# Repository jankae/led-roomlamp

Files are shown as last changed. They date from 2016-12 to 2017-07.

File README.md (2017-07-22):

# led-roomlamp
The led-roomlamp consists of up to six LED spots connected to a central baseplate.
<p align="left">
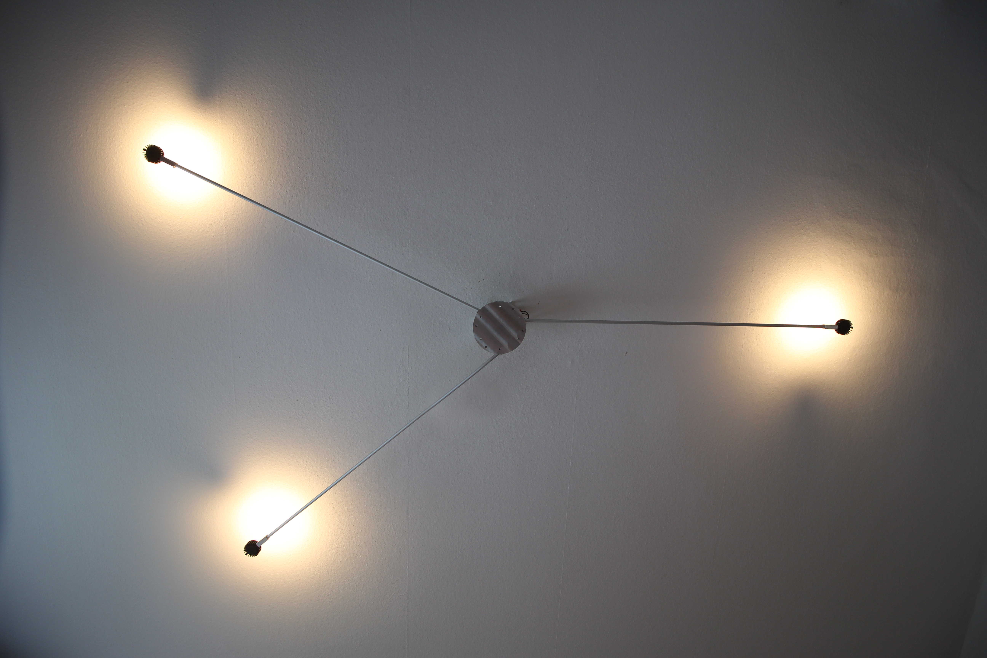
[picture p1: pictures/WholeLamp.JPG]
  
</p>

Each spot features a 10W LED on a heatsink with its own (AVR controller) boost-converter (led-driver):
<p align="left">
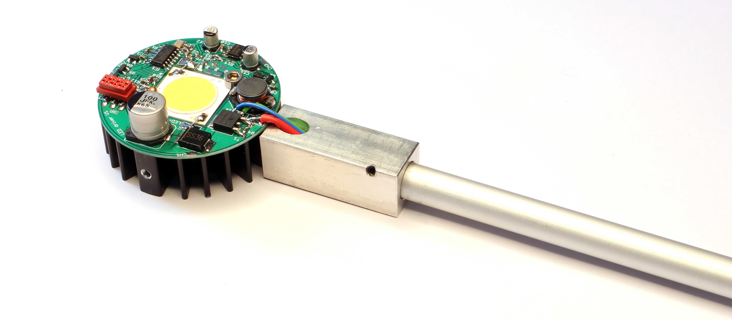
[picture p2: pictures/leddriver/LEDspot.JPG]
  
</p>
The spot needs a 12V supply and can be controlled via I2C. All the spots are connected to the central led-control board on the baseplate:
<p align="left">
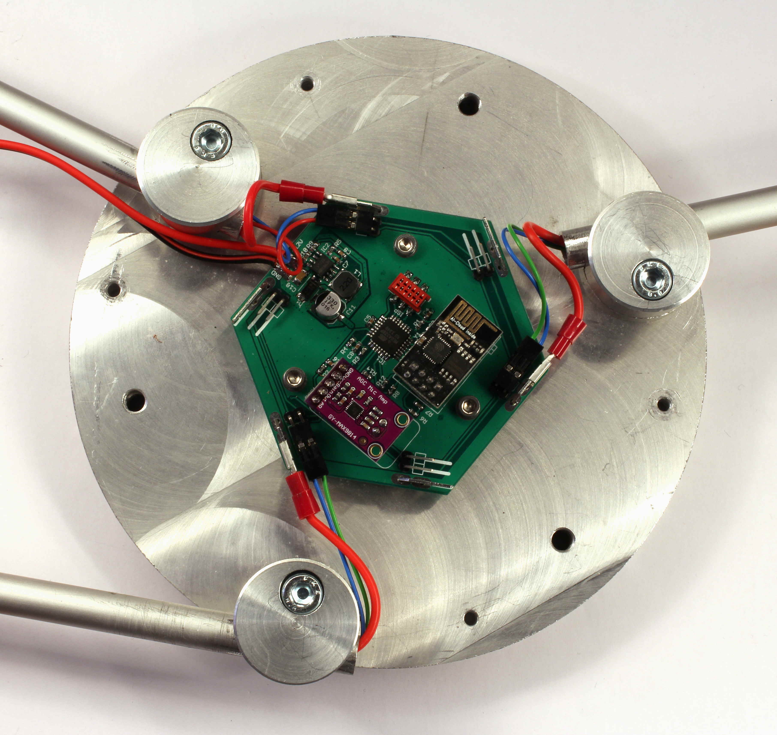
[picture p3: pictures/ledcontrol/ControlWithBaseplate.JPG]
  
</p>
The led-control board essentially is just an ATmega328 with a switching controller, a microphone (one of the available MAX9814 breakout-boards) and (optionally) an ESP-01.

The controller continuously samples the microphone, performs an FFT and identifies whistle tones. By whistling different frequencies, the brightness of the lamp can be controlled.

Alternatively, the lamp can be controlled via UART (38400 Baud) which is connected to the ESP. Using the [ESP-link](https://github.com/jeelabs/esp-link) firmware, commands can be send via WiFi. Send 'help' to retrieve a list of available commands.

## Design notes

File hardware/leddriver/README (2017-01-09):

As usual, the first revision (V1) of the board includes some mistakes.
These are the necessary fixes (see fixesV1.JPG):

1. Do not populate R2.
2. Do not populate R14.
3. Do not populate Q3. Instead short its base and collector and add a resistor of approx. 10k between the emitter and collector.
4. Add a 100nF capacitor from IC1 pin 13 to ground.
5. Add a 100nF capacitor on top of R9.
6. Add a 100nF capacitor on top of R12.
7. Add a 1k resistor from R15 to ground.

These are fixed in V1.1. But since V1 is working well, V1.1 will probably never be build, is therefore untested and might contain further errors.

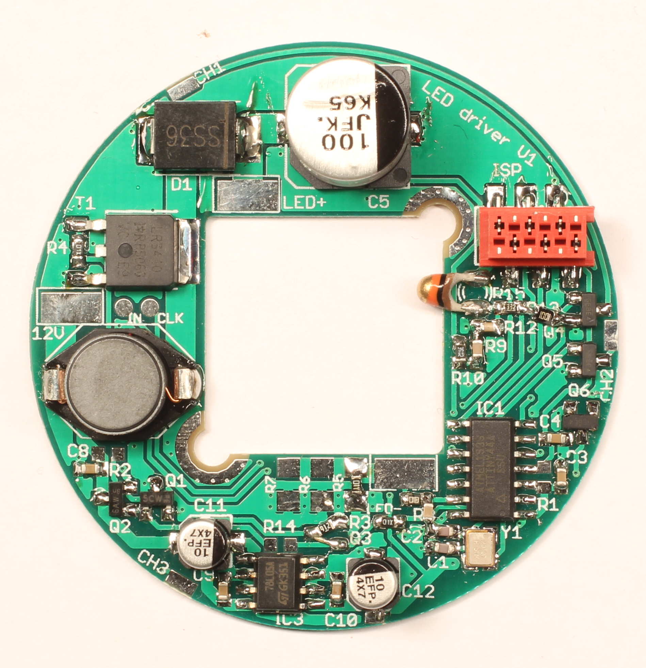
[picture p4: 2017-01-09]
pictures/leddriver/leddriverV1.JPG

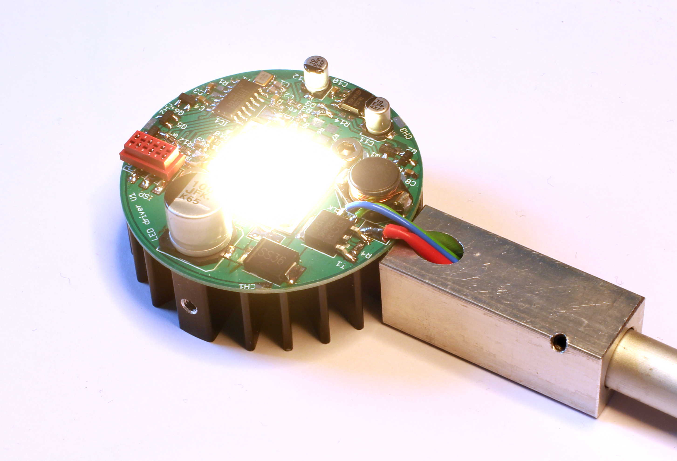
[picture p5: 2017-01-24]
pictures/leddriver/LEDon.JPG

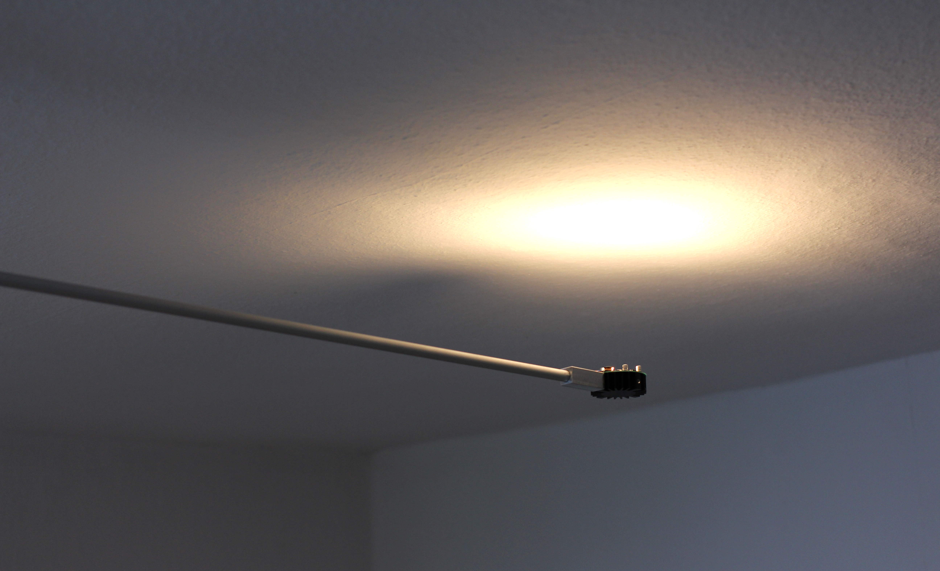
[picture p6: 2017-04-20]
pictures/Spot.JPG

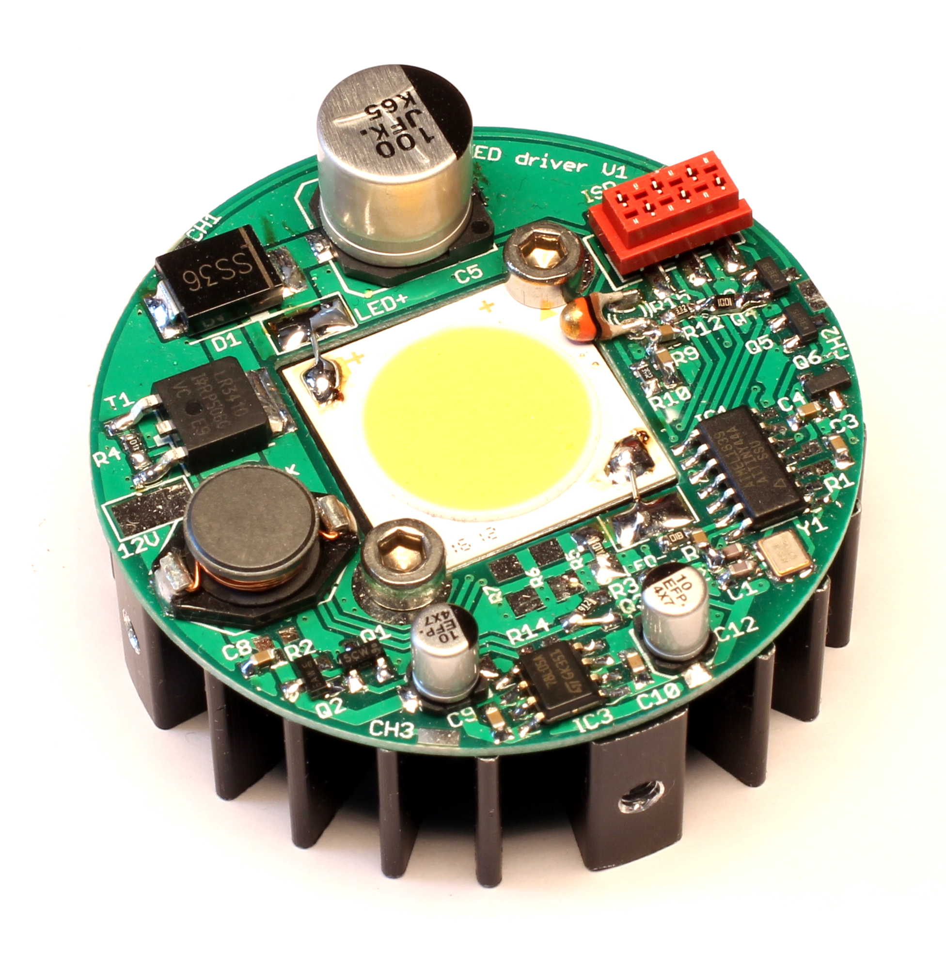
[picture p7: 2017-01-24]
pictures/leddriver/PCBonHeatsink.JPG

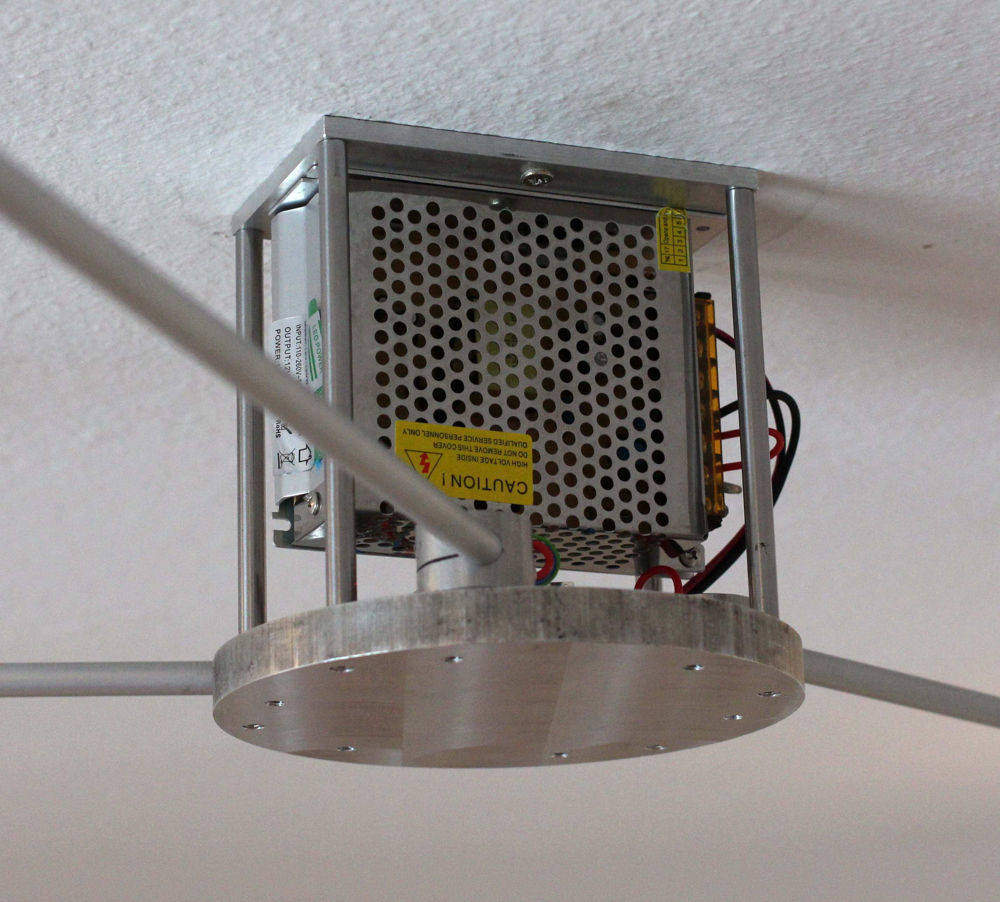
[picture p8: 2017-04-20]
pictures/Base.JPG

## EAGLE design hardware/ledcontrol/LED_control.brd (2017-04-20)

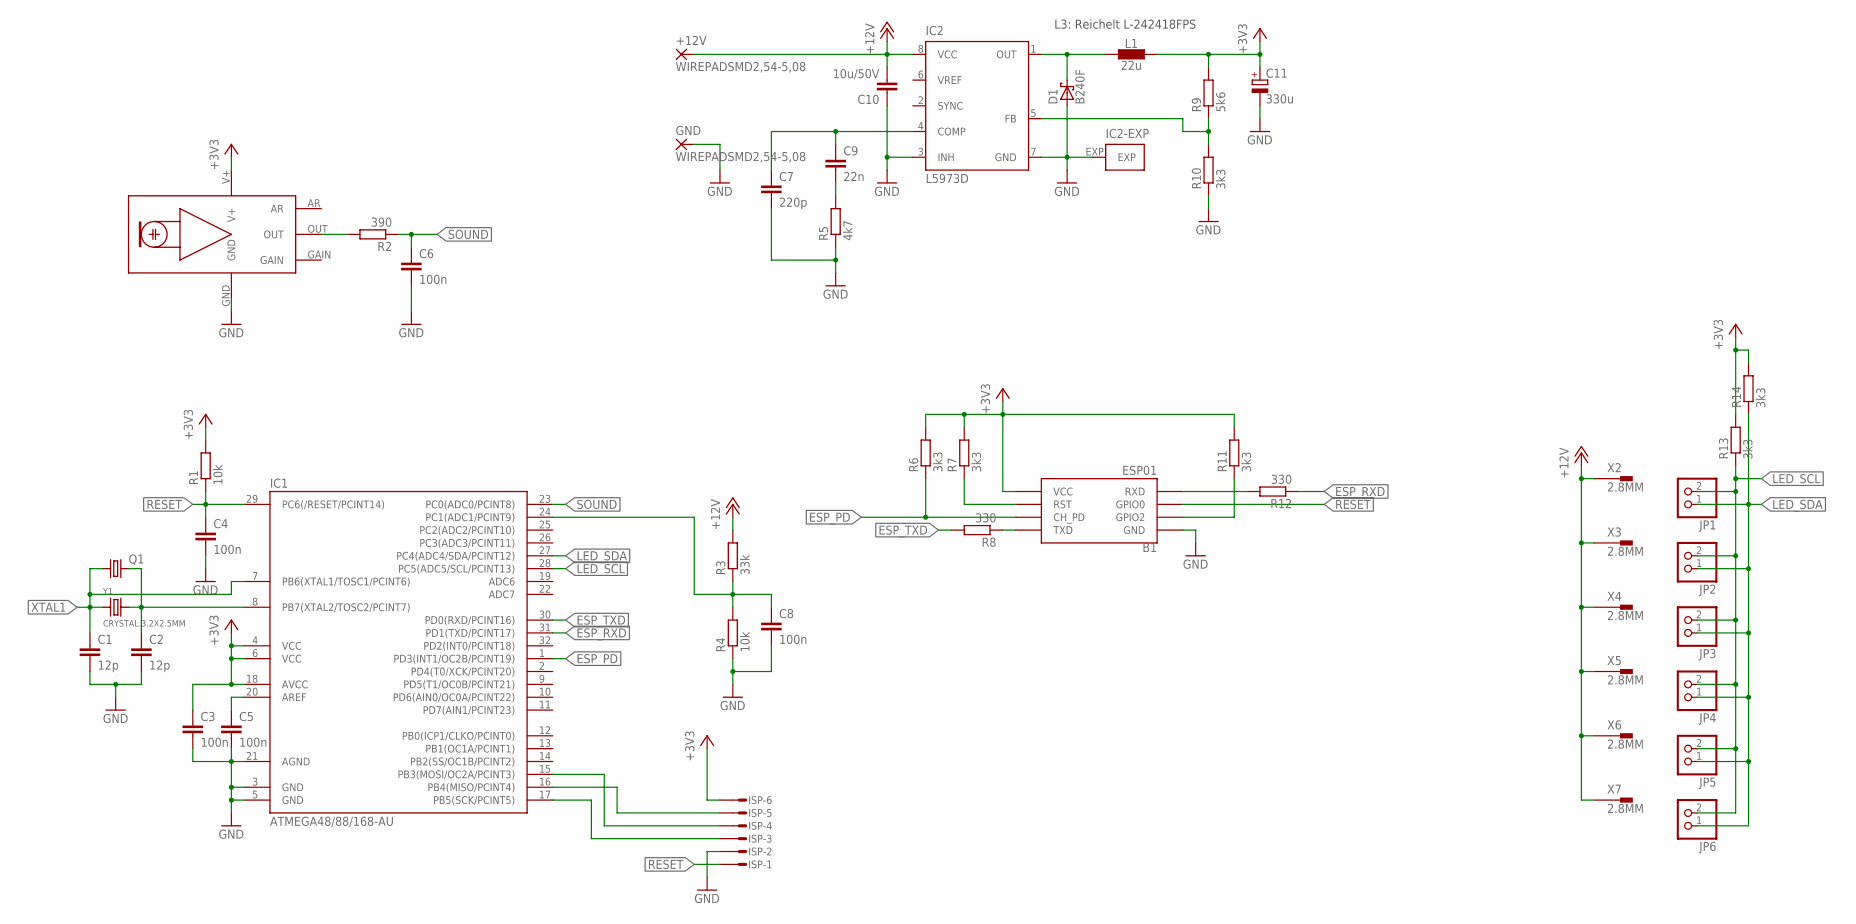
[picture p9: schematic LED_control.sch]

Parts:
+12V: WIREPADSMD2,54-5,08; SMD2,54-5,08
B1: ESP01
C1, C2: 12p; C0603K
C3, C5, C6: 100n; C0603K
C4, C8: 100n; C0603
C7: 220p; C0603
C9: 22n; C0603
C10: 10u/50V; C1206
C11: 330u; 153CLV-0605
D1: B240F; SMB
GND: WIREPADSMD2,54-5,08; SMD2,54-5,08
IC1: ATMEGA48/88/168-AU; TQFP32-08
IC2: L5973D; HSOP8
ISP: MICROMATCH-6SMF; MMT-F-SMD-6
JP1, JP2, JP3, JP4, JP5, JP6: PINHD-1X2/90; 1X02/90
L1: 22u; L_NR60XX
PCB1: MAX9814_AGC_MIC
Q1: CRYSTALHC49S; HC49/S
R1, R4: 10k; R0603
R2: 390; R0603
R3: 33k; R0603
R5: 4k7; R0603
R6, R7, R10, R11, R13, R14: 3k3; R0603
R8, R12: 330; R0603
R9: 5k6; R0603
X2, X3, X4, X5, X6, X7: 2.8MM; 2.8_90
Y1: CRYSTAL.3.2X2.5MM; 3.2X2.5MM

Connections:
+3V3: B1.VCC, C3.1, C11.+, IC1.4 (VCC), IC1.6 (VCC), IC1.18 (AVCC), ISP.6, L1.2, PCB1.V+, R1.2, R6.2, R7.2, R9.2, R11.2, R13.2, R14.2
+12V: +12V.1, C10.2, IC2.8 (VCC), R3.2, X2.1A, X2.1B, X3.1A, X3.1B, X4.1A, X4.1B, X5.1A, X5.1B, X6.1A, X6.1B, X7.1A, X7.1B
ESP_GPIO2: B1.GPIO2, R11.1
ESP_PD: B1.CH_PD, IC1.1 (PD3(INT1/OC2B/PCINT19)), R6.1
ESP_RST: B1.RST, R7.1
ESP_RXD: IC1.31 (PD1(TXD/PCINT17)), R12.1
ESP_TXD: IC1.30 (PD0(RXD/PCINT16)), R8.2
GND: B1.GND, C1.2, C2.2, C3.2, C4.2, C5.2, C6.2, C7.2, C8.2, C10.1, C11.-, D1.A, GND.1, IC1.3 (GND), IC1.5 (GND), IC1.21 (AGND), IC2.3 (INH), IC2.7 (GND), IC2.EXP, ISP.2, PCB1.GND, R4.1, R5.1, R10.1
LED_SCL: IC1.28 (PC5(ADC5/SCL/PCINT13)), JP1.2, JP2.2, JP3.2, JP4.2, JP5.2, JP6.2, R13.1
LED_SDA: IC1.27 (PC4(ADC4/SDA/PCINT12)), JP1.1, JP2.1, JP3.1, JP4.1, JP5.1, JP6.1, R14.1
MISO: IC1.16 (PB4(MISO/PCINT4)), ISP.5
MOSI: IC1.15 (PB3(MOSI/OC2A/PCINT3)), ISP.4
unnamed: B1.RX (RXD), R12.2
unnamed: B1.TX (TXD), R8.1
unnamed: C5.1, IC1.20 (AREF)
unnamed: PCB1.OUT, R2.2
unnamed: C8.1, IC1.24 (PC1(ADC1/PCINT9)), R3.1, R4.2
unnamed: C7.1, C9.1, IC2.4 (COMP)
unnamed: C9.2, R5.2
unnamed: D1.C, IC2.1 (OUT), L1.1
unnamed: IC2.5 (FB), R9.1, R10.2
RESET: B1.GPIO0, C4.1, IC1.29 (PC6(/RESET/PCINT14)), ISP.1, R1.1
SCK: IC1.17 (PB5(SCK/PCINT5)), ISP.3
SOUND: C6.1, IC1.23 (PC0(ADC0/PCINT8)), R2.1
XTAL1: C1.1, IC1.7 (PB6(XTAL1/TOSC1/PCINT6)), Q1.1, Y1.1
XTAL2: C2.1, IC1.8 (PB7(XTAL2/TOSC2/PCINT7)), Q1.2, Y1.3 (2)

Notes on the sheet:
L3: Reichelt L-242418FPS

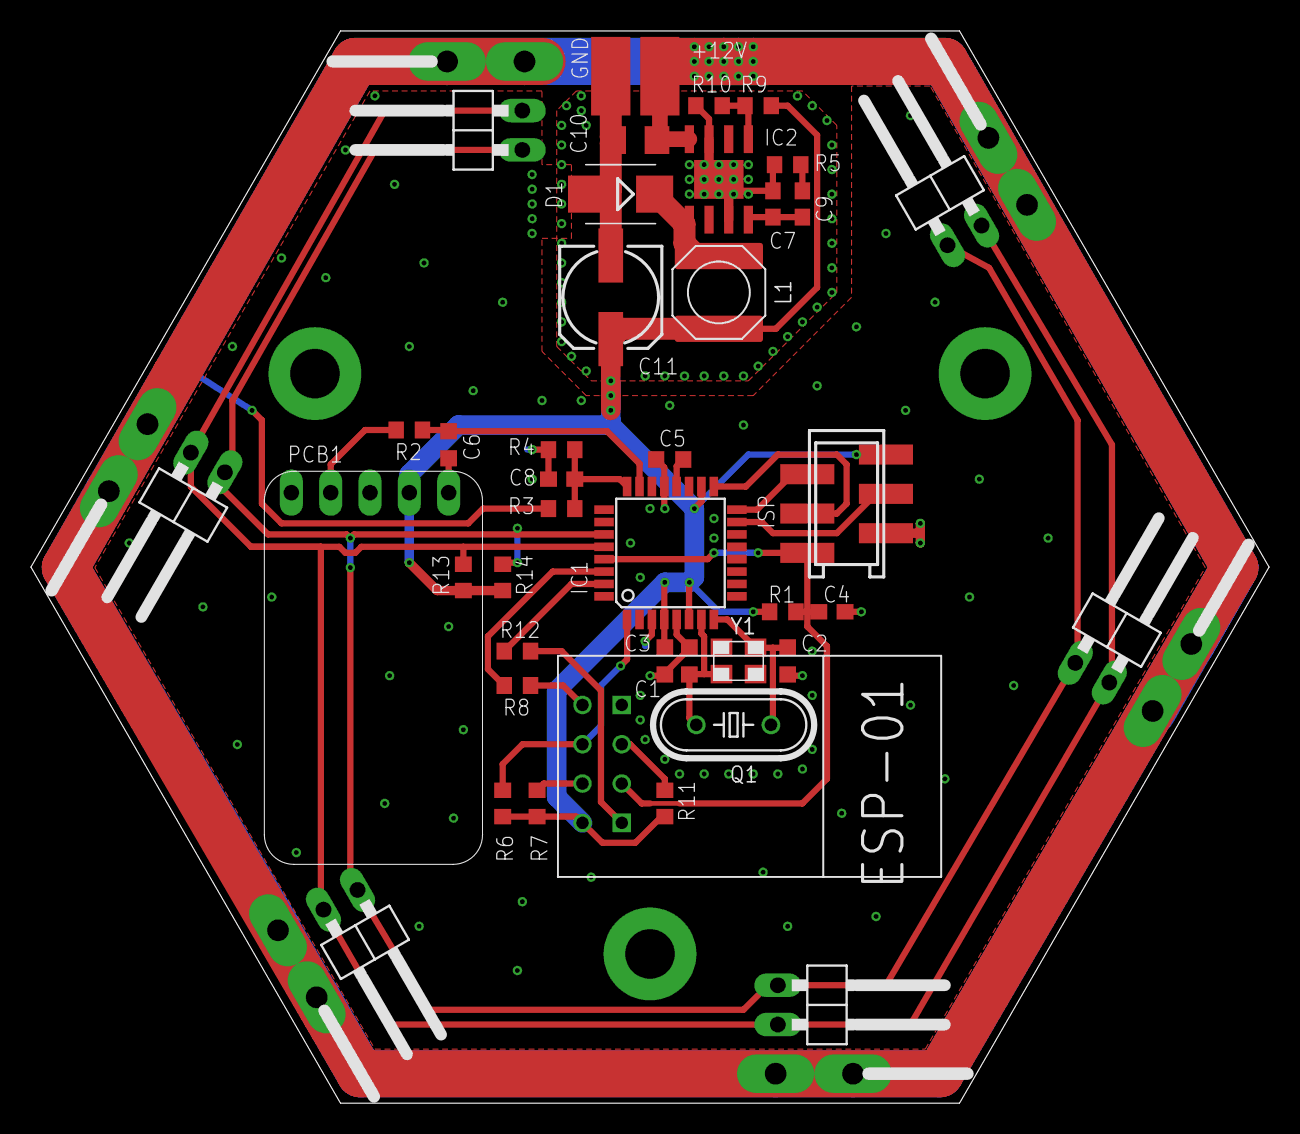
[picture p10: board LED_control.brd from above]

Board: 2 copper layers, 80.0 x 69.3 mm, 48 parts (0 on the bottom side), 26 nets.

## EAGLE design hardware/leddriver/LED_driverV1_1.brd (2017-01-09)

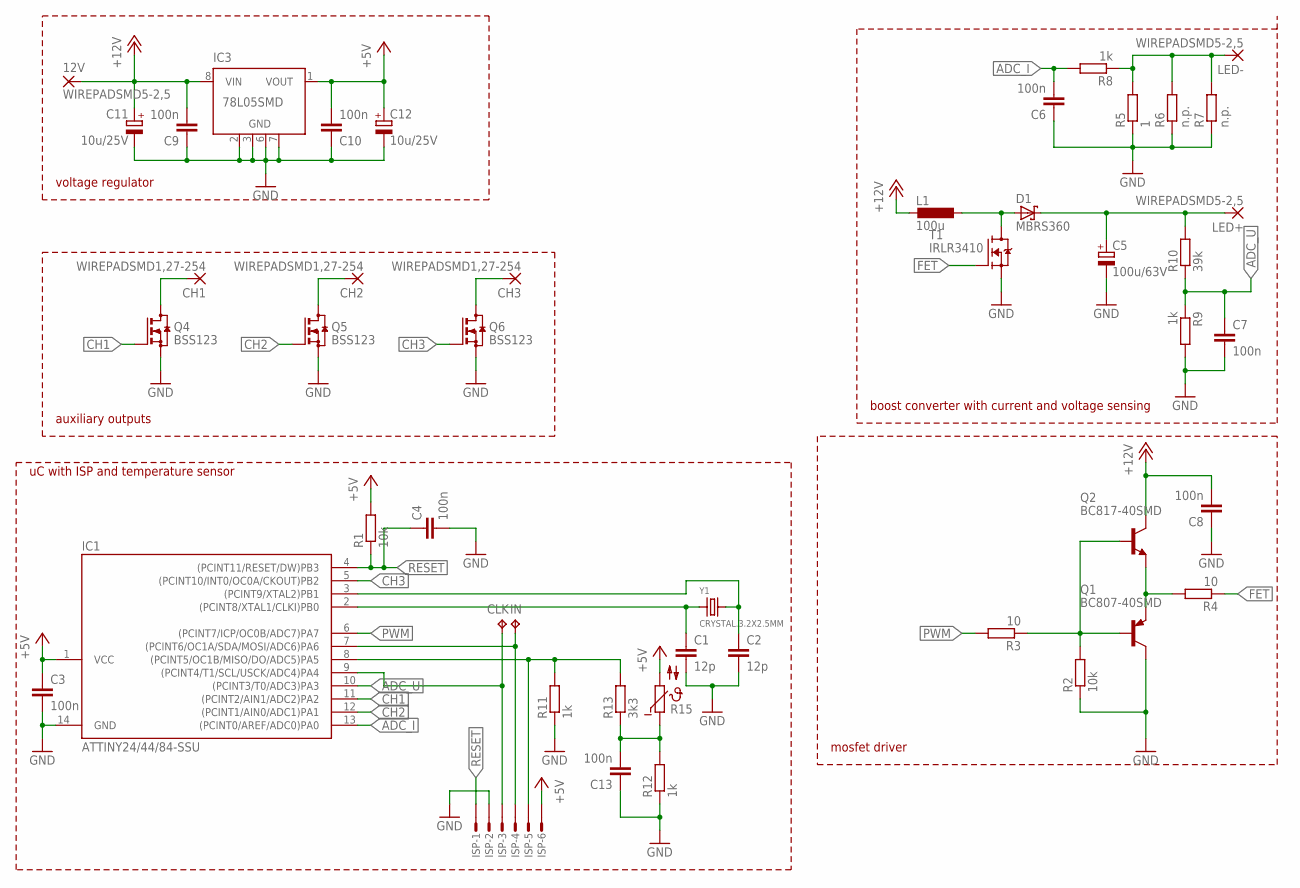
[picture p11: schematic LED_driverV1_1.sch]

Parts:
12V: WIREPADSMD5-2,5; 5-2,5
C1, C2: 12p; C0603K
C3, C4, C6, C7, C8, C9, C10, C13: 100n; C0603K
C5: 100u/63V; 153CLV-1010
C11, C12: 10u/25V; 153CLV-0405
CH1, CH2, CH3: WIREPADSMD1,27-254; SMD1,27-2,54
CLK: TPTP15R; TP15R
D1: MBRS360; SMC
IC1: ATTINY24/44/84-SSU; SOIC14
IC3: 78L05SMD; SO08
IN: TPTP15R; TP15R
ISP: MICROMATCH-6SMF; MMT-F-SMD-6
L1: 100u; PISM
LED+: WIREPADSMD5-2,5; 5-2,5
LED-: WIREPADSMD5-2,5; 5-2,5
Q1: BC807-40SMD; SOT23-BEC
Q2: BC817-40SMD; SOT23-BEC
Q4, Q5, Q6: BSS123; SOT23
R1, R2: 10k; R0603
R3, R4: 10; R0603
R5: 1; R1206
R6, R7: n.p.; R1206
R8, R9, R11, R12: 1k; R0603
R10: 39k; R0603
R13: 3k3; R0603
R15: NTC640; P640
T1: IRLR3410; TO252
Y1: CRYSTAL.3.2X2.5MM; 3.2X2.5MM

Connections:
+5V: C3.1, C10.2, C12.+, IC1.1 (VCC), IC3.1 (VOUT), ISP.6, R1.2, R15.2
+12V: 12V.1, C8.2, C9.2, C11.+, IC3.8 (VIN), L1.2, Q2.C
ADC_I: C6.2, IC1.13 ((PCINT0/AREF/ADC0)PA0), R8.2
ADC_U: C7.1, IC1.10 ((PCINT3/T0/ADC3)PA3), R9.1, R10.1
CH1: IC1.11 ((PCINT2/AIN1/ADC2)PA2), Q4.1 (G)
CH1_OUT: CH1.1, Q4.3 (D)
CH2: IC1.12 ((PCINT1/AIN0/ADC1)PA1), Q5.1 (G)
CH2_OUT: CH2.1, Q5.3 (D)
CH3: IC1.5 ((PCINT10/INT0/OC0A/CKOUT)PB2), Q6.1 (G)
CH3_OUT: CH3.1, Q6.3 (D)
FET: R4.1, T1.1 (G)
GND: C1.2, C2.2, C3.2, C4.2, C5.-, C6.1, C7.2, C8.1, C9.1, C10.1, C11.-, C12.-, C13.1, IC1.14 (GND), IC3.2 (GND), IC3.3 (GND), IC3.6 (GND), IC3.7 (GND), ISP.2, Q1.C, Q4.2 (S), Q5.2 (S), Q6.2 (S), R2.1, R5.1, R6.1, R7.1, R9.2, R11.1, R12.1, T1.2 (S)
LED+: C5.+, D1.C, LED+.1, R10.2
LED-: LED-.1, R5.2, R6.2, R7.2, R8.1
MISO: IC1.8 ((PCINT5/OC1B/MISO/DO/ADC5)PA5), ISP.5, R11.2, R13.2
MOSI: IC1.7 ((PCINT6/OC1A/SDA/MOSI/ADC6)PA6), IN.TP, ISP.4
unnamed: D1.A, L1.1, T1.3 (D)
PP_IN: Q1.B, Q2.B, R2.2, R3.1
PP_OUT: Q1.E, Q2.E, R4.2
PWM: IC1.6 ((PCINT7/ICP/OC0B/ADC7)PA7), R3.2
RESET: C4.1, IC1.4 ((PCINT11/RESET/DW)PB3), ISP.1, R1.1
SCK: CLK.TP, IC1.9 ((PCINT4/T1/SCL/USCK/ADC4)PA4), ISP.3
TEMP: C13.2, R12.2, R13.1, R15.1
XTAL1: C1.1, IC1.2 ((PCINT8/XTAL1/CLKI)PB0), Y1.1
XTAL2: C2.1, IC1.3 ((PCINT9/XTAL2)PB1), Y1.3 (2)

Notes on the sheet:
uC with ISP and temperature sensor
auxiliary outputs
voltage regulator
boost converter with current and voltage sensing
mosfet driver

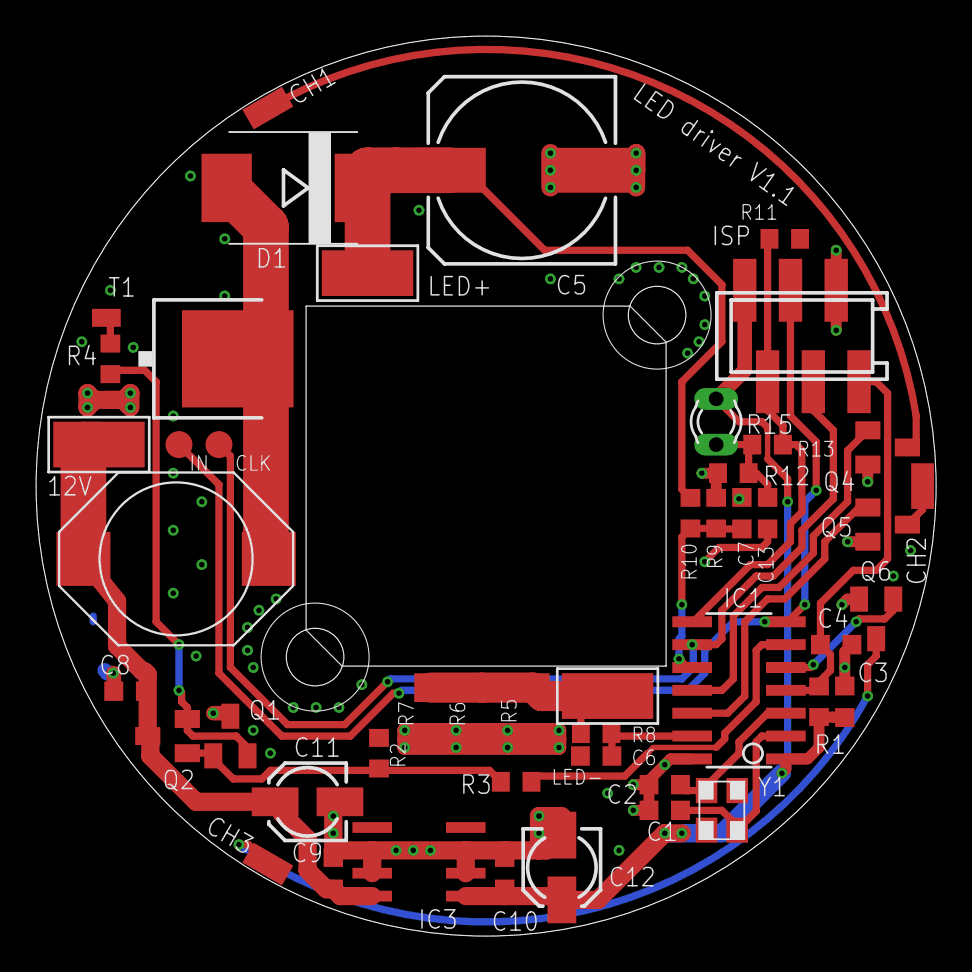
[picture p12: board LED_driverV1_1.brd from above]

Board: 2 copper layers, 50.0 x 50.0 mm, 47 parts (0 on the bottom side), 25 nets.

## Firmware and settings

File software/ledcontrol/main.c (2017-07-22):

#include <avr/io.h>
#include "shell.h"
#include "timing.h"
#include "adc.h"

int main(void){
	wdt_disable();
	timing_Init();
	uart_Init();
	ADC_Init();
	sei();

	uart_sendString_P(PSTR("led-control\n"));

	i2c_Init();
	shell_Init();

	timing_Wait(10);

	led_Search();

	/* Turn all spots on */
	uint8_t i;
	for (i = 0; i < led.num; i++) {
		uint8_t address = led.addresses[i];
		led_SetCurrent(address, 250);
		timing_Wait(1);
		led_UpdateSettings(address);
		timing_Wait(1);
	}

	uint8_t consecutivePeaks = 0;
#define MIN_CONSEC_PEAKS		10
	while (1) {
		shell_Update();
		if (adc.enabled && adc.newData) {
			/* store new measurement */
			uint16_t freq = ADC_PeakSearch();
			if (freq > 750) {
				if (consecutivePeaks < UINT8_MAX)
					consecutivePeaks++;
			} else {
				consecutivePeaks = 0;
			}
			if (consecutivePeaks >= MIN_CONSEC_PEAKS) {
				uint16_t current = 0;
				if (freq > 2000) {
					current = LED_MAX_CURRENT;
				} else if (freq > 1000) {
					freq -= 1000;
					uint32_t freqSquared = (uint32_t) freq * freq / 1000;
					current = freqSquared * LED_MAX_CURRENT / 1000;
				}
				uint8_t i;
				for (i = 0; i < led.num; i++) {
					uint8_t address = led.addresses[i];
					led_SetCurrent(address, current);
					timing_Wait(1);
					led_UpdateSettings(address);
					timing_Wait(1);
				}
			}
		}
	}
}

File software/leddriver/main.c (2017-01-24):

/**
 * \file
 */
#include <avr/io.h>
#include <avr/sleep.h>

#include "boost.h"
#include "channels.h"
#include "adc.h"
#include "usi.h"
#include <util/delay.h>
#include "usi.h"

#define VERSION		1

int main(void){
	boost_Init();
	channels_Init();
	adc_Init();
	usi_InitI2C(I2C_ADDRESS);

	/* disable analog comparator */
	ACSR |= (1<<ACD);

	usi.ledData.version = VERSION;

	/* everything is set up, interrupts will take care of the rest */
	sei();

	while (1) {
		if(usi.ledData.control & USI_CTRL_UPDATE){
			/* new data received -> update boost converter */
			cli();
			/* copy data atomically */
			uint16_t current = usi.ledData.setCurrent;
			uint16_t voltage = usi.ledData.setVoltage;
			uint8_t temp = usi.ledData.tempLimit;
			/* clear new data flag */
			usi.ledData.control &= ~USI_CTRL_UPDATE;
			sei();
			/* set new limits for boost converter */
			boost_setCurrent(current);
			boost_setMaxVoltage(voltage);
			boost_setMaxTemperature(temp);
			if (current > 0) {
				boost.active = 1;
			} else {
				boost.active = 0;
			}
			/* update channel values */
			channels_Update(usi.ledData.channel1, usi.ledData.channel2,
					usi.ledData.channel3);
		}
		if (adc.newData) {
			boost_Update();
			adc.newData = 0;
			/* update values in USI registers */
			cli();
			if(usi.state == USI_SLAVE_IDLE){
				/* only update 16 bit values if no transaction is active */
				usi.ledData.dutyIndex = boost.dutyCycleIt;
				usi.ledData.getCurrent = boost.current;
				usi.ledData.getVoltage = boost.voltage;
			}
			sei();
			/* 8 bit values may always be updated */
			usi.ledData.compareReg = OCR0B;
			usi.ledData.topReg = OCR0A;
			usi.ledData.temperature = boost.temperature;
		}
		/* Stop condition doesn't trigger an interrupt -> poll it */
		usi_CheckForStop();

		set_sleep_mode(SLEEP_MODE_IDLE);
		sleep_mode()
		;
	}
}

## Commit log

2016-12-20 initial LED driver schmematic+layout
    [LED_driver.brd, LED_driver.sch]
2016-12-21 callback in ADC interrupt
2016-12-25 added make assember to makefile to view assembly
2017-01-02 added datasheets
    [LED_driver.brd, LED_driver.sch]
2017-01-02 remove duplicate board files
    [LED_driver.brd, LED_driver.sch]
2017-01-03 temperature limit implemented
2017-01-04 some fixes + toggle macro added
    [channels.h]
2017-01-04 fixed registers and naked ISR removed
    OCR0x registers are double buffered -> not necessary anymore
    [boost.h]
2017-01-04 lots of changes
    - ADC averaging
    - ADC callback replaced by flag
    - Temperature scale adapted to 1V1 reference
    [adc.c, adc.h, boost.h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]
2017-01-05 Software UART for debugging
2017-01-05 PWM pin changed to non-inverting, current control refined
2017-01-05 some bugfixes in serial protocol
    [usi.h]
2017-01-05 Support for current changing via SPI
2017-01-06 Serial protocol changed from SPI to I2C
2017-01-06 boost struct values changed from raw ADC to meaningful units
    - current now in mA
    - voltage now in mV
    - temperature in °C
    - temperature calculation via lookup-table and interpolation
    - python script for generating temperatur lookup-table
2017-01-06 PWM lookup extended again + bugfixes in main
    [boost.h, main.c]
2017-01-07 [ledcontrol] initial setup, basic UART shell
2017-01-07 i2c scan command added + some bugfixes
    [command.c, i2c.c, main.c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]
2017-01-08 inlined i2c_stop
2017-01-08 i2c read/write command
2017-01-08 basic LED control functions
2017-01-08 uart send value function
2017-01-08 ledstats command
2017-01-08 send unsigned value via uart
2017-01-08 ledset command
2017-01-08 [leddriver] USI control struct with readable names instead of registers
2017-01-08 [ledcontrol/command] bugfix: renamed option
    [command.c]
2017-01-08 [leddriver] hysteresis for temperature limit
2017-01-08 [leddriver] temperature averaging, PWM lookup size reduced
2017-01-09 Hardware fixes + probably fixed PCB layout
    [LED_driverV1.brd, LED_driverV1.sch, LED_driverV1_1.brd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]
2017-01-09 [leddriver] i2c fix (works so far)
2017-01-09 First picture of leddriver PCB
2017-01-09 [leddriver] Soft PWM added
2017-01-10 [leddriver] soft PWM bugfixes
    [channels.c]
2017-01-10 [ledcontrol] soft PWM protocol support
2017-01-24 Uart automations
    - Baud rate calculation using util/setbaud
    - Support for ATmega8/ATmega1284p
2017-01-24 Switched back to ATmega1284p
2017-01-24 I2C bitrate checks
2017-01-24 Uart defines simplified
2017-01-24 I2C timeouts
2017-01-24 Search LED spots and only do I2C operations on these addresses
2017-01-24 reset USI when switching to idle
2017-01-24 Set I2C address in makefile
2017-01-24 print time command
2017-01-24 Some pictures of the assembled LED spot
2017-02-09 ADC and FFT functions
2017-02-09 Minor corrections + memory saving stuff (running out of FLASH in mega8)
    [adc.c, adc.h, command.c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]
2017-04-20 ledcontrol PCB files
    [LED_control.brd, LED_control.sch]
2017-04-20 led control adjusted to mega328
